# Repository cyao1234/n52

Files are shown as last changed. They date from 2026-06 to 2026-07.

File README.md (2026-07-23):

# n52 stamp

nRF52 stamp devboard with castellated holes on all 3 edges and a low profile,
allowing it to be easily soldered onto a carrier board, without having to deal with
the aQFN nRF52840 footprint. The board breaks out 36 I/O pins, and also has an
embedded 24 pin e-ink connector.

The board can operate standalone for direct wireless communication with host devices, or function as a carrier board for more complex projects. Key features include low current consumption, easy usability, and a streamlined design that prioritizes rapid prototyping and deployment.

The board's 36 broken-out I/O pins provide extensive flexibility for sensor integration, peripheral control, and data communication.

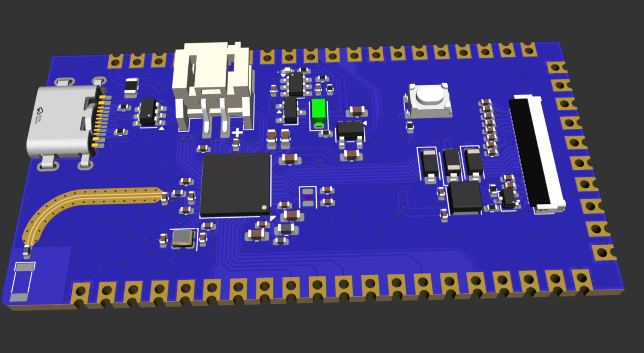
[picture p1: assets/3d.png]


Features:
- Integrated power path
- LiPo charger
- Eink driver
- Low current consumption
- Easy to use
- Castellated edges

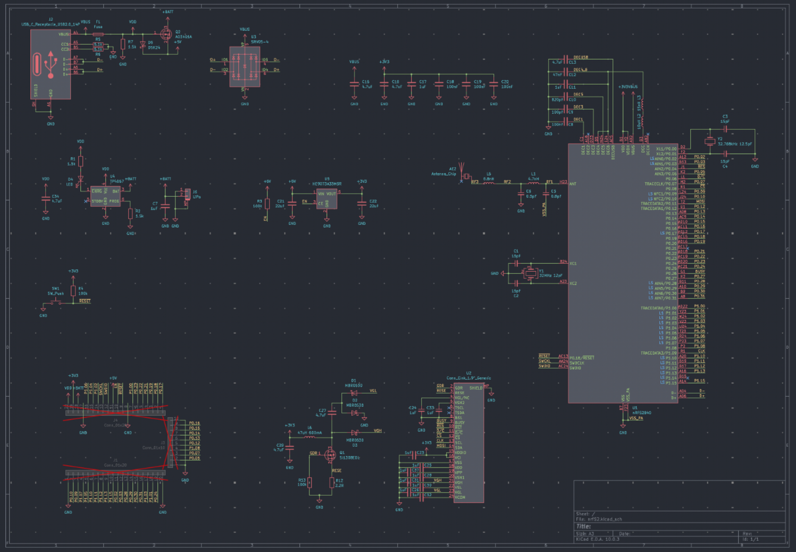
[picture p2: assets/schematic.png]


The board uses a nrf52 design to allow for bluetooth communication, and has all that is needed to directly communicate via bluetooth to a host. No external parts needed, but it can also act as an carrier board

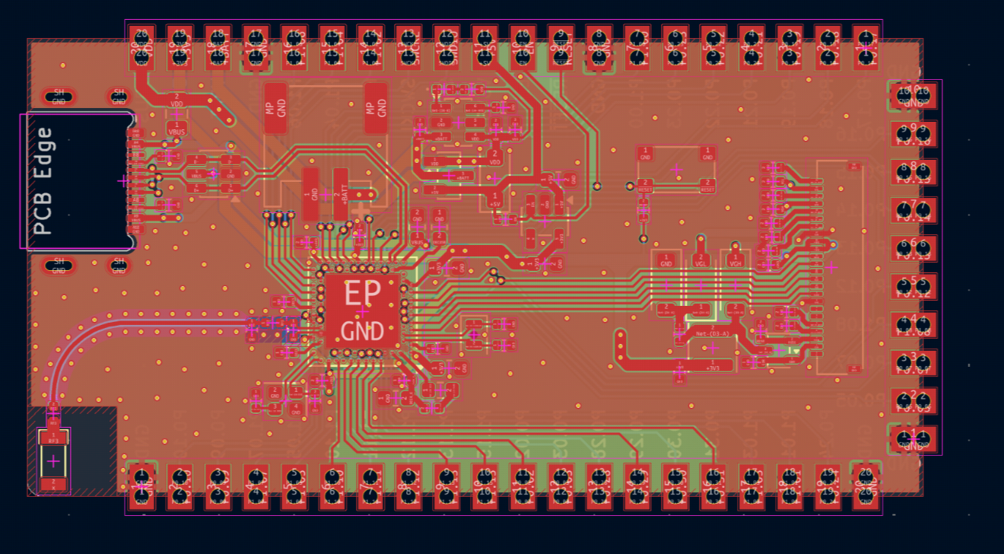
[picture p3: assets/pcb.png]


Pins:
* LED0 = P0.18
* LED1 = P0.17
* E-Ink
  * BUSY   = P0.26
  * nRESET = P0.04
  * nD/C   = P0.06
  * nCS    = P0.08
  * CLK    = P1.09
  * MOSI   = P0.11

The best way to program the board and use it is to use [Zephyr](https://docs.zephyrproject.org/)

All sources are present in the repo



| Item | Cost | Where |
| ---- | ---- | ----- |
| PCB + PCBA | $160 | JLC |

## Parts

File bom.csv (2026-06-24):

Item | Cost | Where
PCB PBCA | $160 | jlc

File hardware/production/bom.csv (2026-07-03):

Designator | Footprint | Quantity | Value | LCSC Part #
AE2 | Walsin_RFANT3216120A5T | 1 | Antenna_Chip | C127629
C1, C2, C3, C4 | 0402 | 4 | 15pF | C1548
C10 | 0402 | 1 | 820pF | C107031
C11, C17, C23, C24, C25, C26, C28, C30, C31, C32, C33, C37, C7 | 0402 | 13 | 1uF | C7472946
C12 | 0402 | 1 | 47nF | C272875
C13, C15, C16 | 0603 | 3 | 4.7uF | C380325
C18, C19, C20, C8 | 0402 | 4 | 100nF | C1525
C21, C22 | 0603 | 2 | 22uF | C380323
C27, C29, C34 | 0402 | 3 | 4.7uF | C380302
C5 | 0402 | 1 | 0.8pF | C76915
C6 | 0402 | 1 | 0.5pF | C76912
C9 | 0402 | 1 | 100pF | C1546
D1, D2, D3 | D_SOD-123 | 3 | MBR0530 | C7436545
D4, D6, D7 | 0402 | 3 | LED | C51933306
D5 | D_SOD-123F | 1 | DSK24 | C22466352
F1 | 0805 | 1 | Fuse | C46640991
J2 | USB_C_Receptacle_SHOU-HAN_TYPE-16P | 1 | USB_C_Receptacle_USB2.0_14P | C2906290
J6 | HCTL_JST_PH_HC-PH-2AWT-B_2P | 1 | LiPo | C19633668
L1 | 0402 | 1 | 4.7nH | C86065
L2 | 0603 | 1 | 10uH | C281107
L3 | 0402 | 1 | 15nH | C86059
L5 | 0402 | 1 | 6.8nH | C96056
L6 | L_APV_ANR3015 | 1 | 47uH 500mA | C7427088
Q1 | SOT-323_SC-70 | 1 | Si1308EDL | C7603347
Q2 | SOT-23 | 1 | AO3401A | C347476
R1, R11, R2, R7, R8 | 0402 | 5 | 1.5k | C114451
R12 | 0402 | 1 | 2.2R | C2906922
R13 | 0402 | 1 | 1M | C93949
R3, R4 | 0402 | 2 | 100k | C481918
R5, R6 | 0402 | 2 | 5.1k | C2906874
SW1 | SW_Push_SPST_TSA016 | 1 | SW_Push | C2888428
U1 | Nordic_AQFN-73-1EP_7x7mm_P0.5mm_Small | 1 | nRF52840 | C190794
U2 | HCTL_HC-FPC-05-09-24RLTAG-1MP_P0.5mm_Horizontal | 1 | Conn_Eink_1.9"_Generic | C5213757
U3 | SOT-23-6 | 1 | SRV05-4 | C2836319
U4 | TSOT-23-6 | 1 | TP4057 | C5380673
U5 | SOT-23-5 | 1 | HE9073A33M5R | C723789
Y1 | Crystal_SMD_2016-4Pin_2.0x1.6mm | 1 | 32MHz 12pF | C383840
Y2 | Crystal_SMD_2012-2Pin_2.0x1.2mm | 1 | 32.768kHz 12.5pF | C55208

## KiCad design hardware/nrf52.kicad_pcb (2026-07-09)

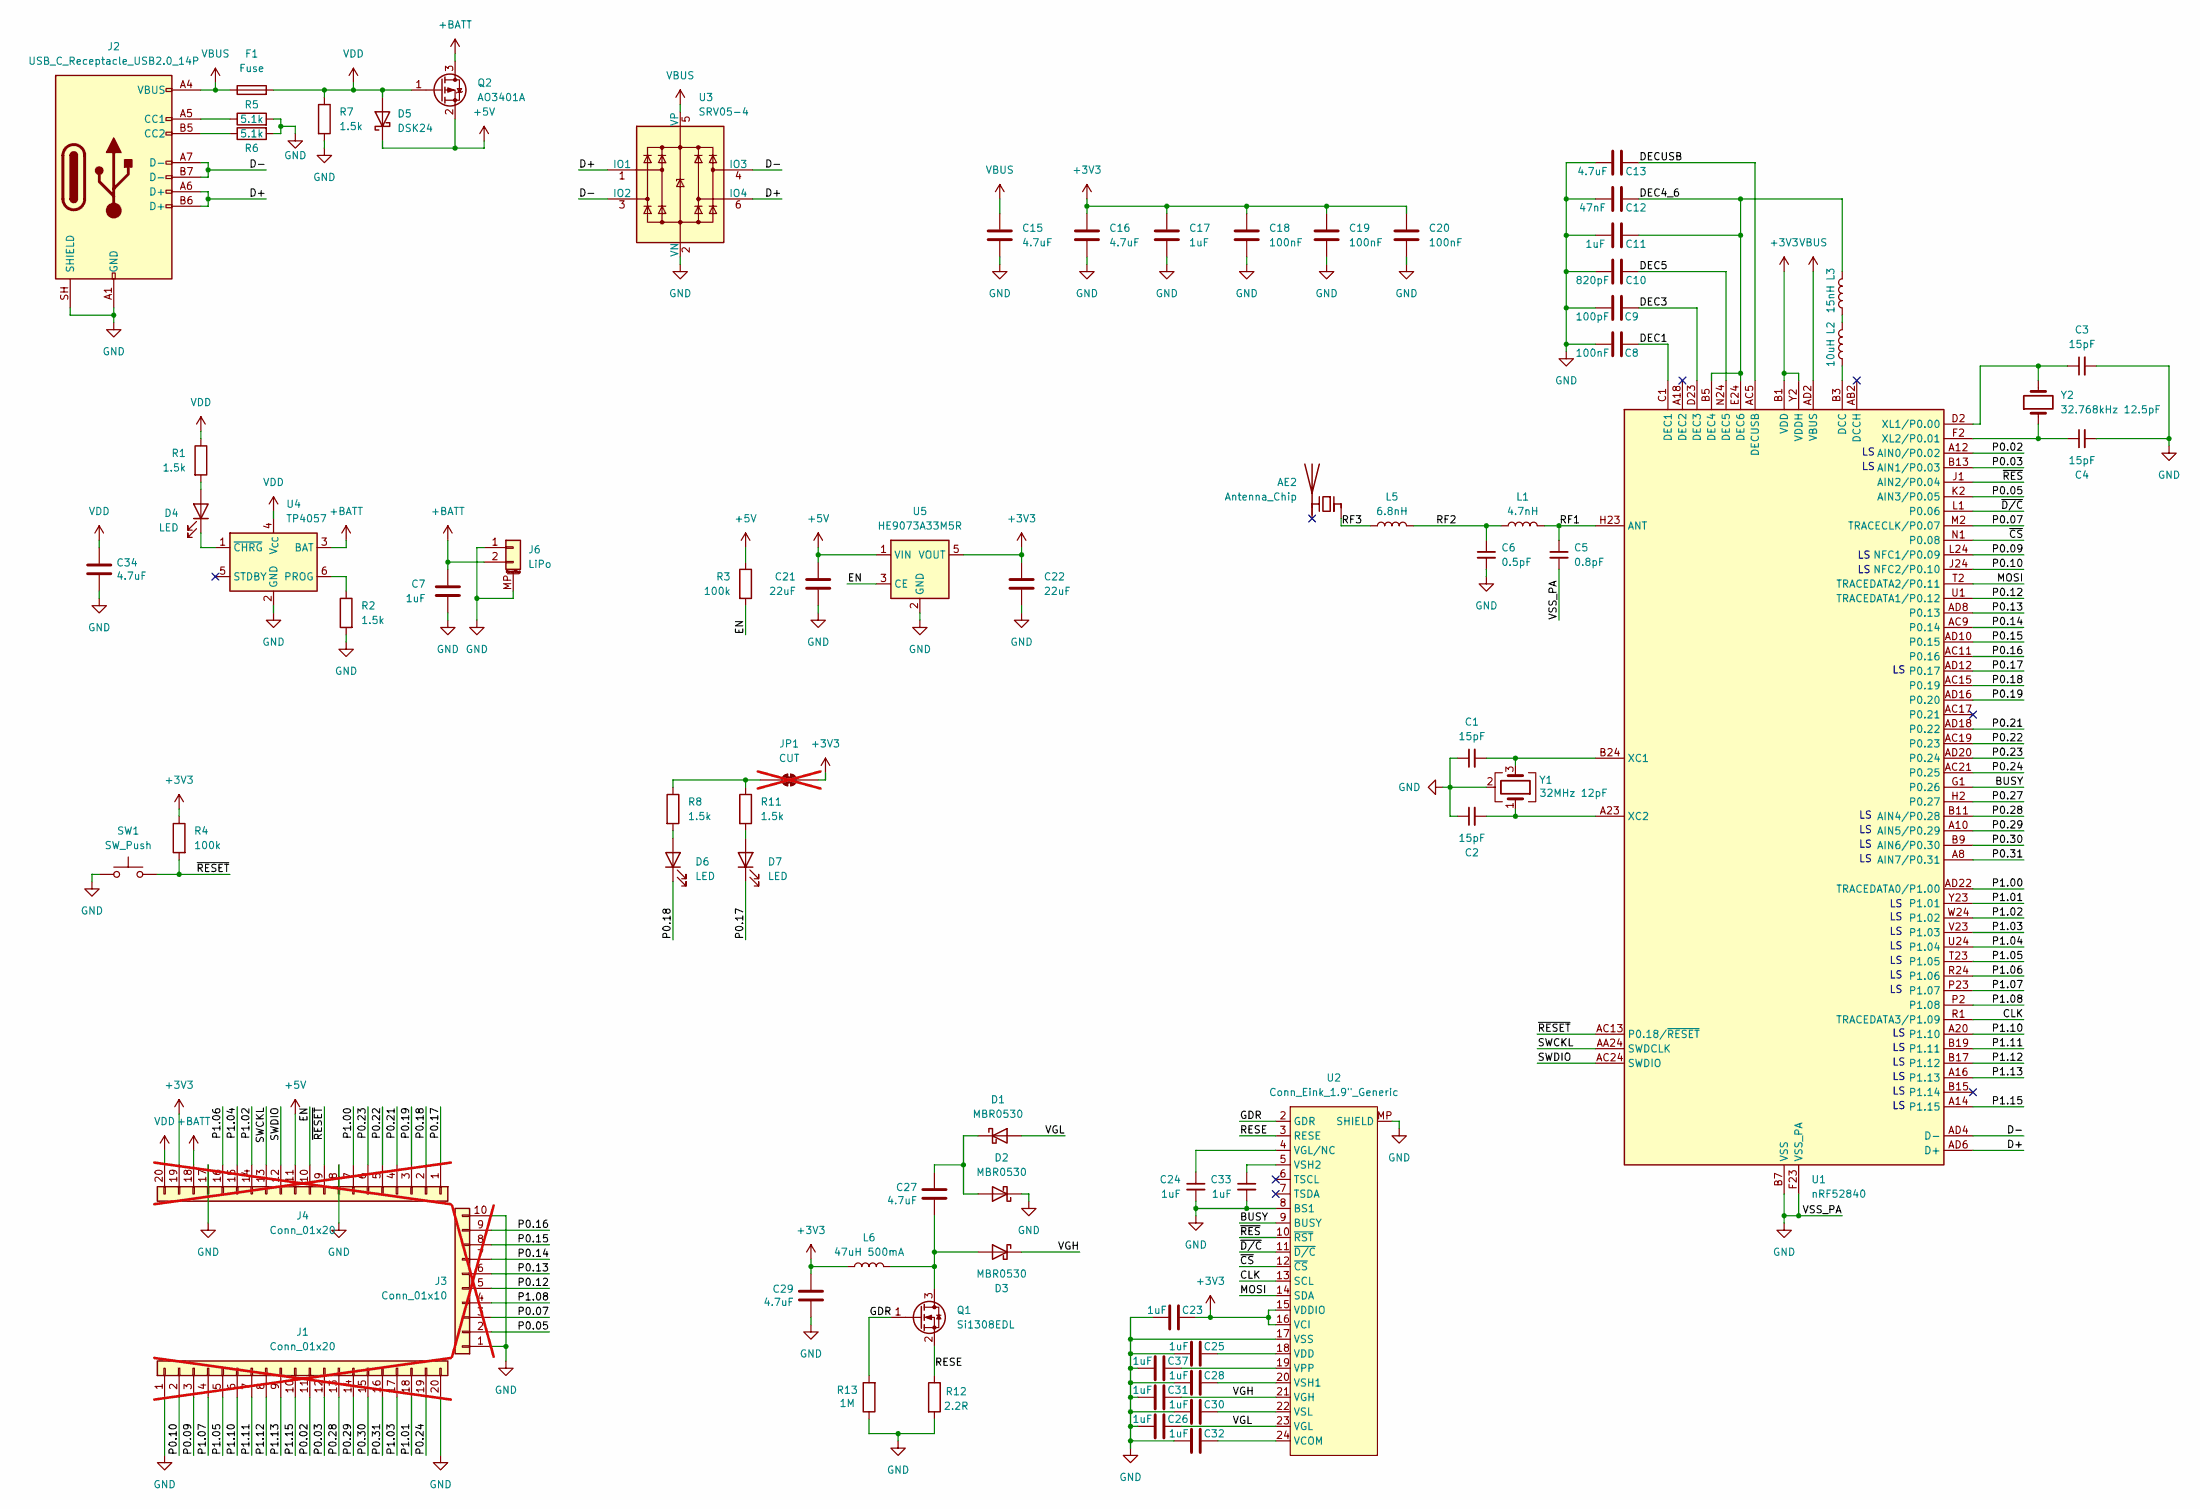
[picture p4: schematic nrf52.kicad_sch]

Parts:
AE2: Antenna_Chip; Walsin_RFANT3216120A5T; LCSC Part # C127629
C1, C2, C3, C4: 15pF; C_0402_1005Metric; LCSC Part # C1548
C5: 0.8pF; C_0402_1005Metric; LCSC Part # C76915
C6: 0.5pF; C_0402_1005Metric; LCSC Part # C76912
C7, C11, C17, C23, C24, C25, C26, C28, C30, C31, C32, C33, C37: 1uF; C_0402_1005Metric; LCSC Part # C7472946
C8, C18, C19, C20: 100nF; C_0402_1005Metric; LCSC Part # C1525
C9: 100pF; C_0402_1005Metric; LCSC Part # C1546
C10: 820pF; C_0402_1005Metric; LCSC Part # C107031
C12: 47nF; C_0402_1005Metric; LCSC Part # C272875
C13, C15, C16: 4.7uF; C_0603_1608Metric; LCSC Part # C380325
C21, C22: 22uF; C_0603_1608Metric; LCSC Part # C380323
C27, C29, C34: 4.7uF; C_0402_1005Metric; LCSC Part # C380302
D1, D2, D3: MBR0530; D_SOD-123; LCSC Part # C7436545
D4, D6, D7: LED; LED_0402_1005Metric; LCSC Part # C51933306
D5: DSK24; D_SOD-123F; LCSC Part # C22466352
F1: Fuse; Fuse_0805_2012Metric; LCSC Part # C46640991
J1, J4: Conn_01x20; Castellated_1x20_P2.54mm_Vertical; not fitted
J2: USB_C_Receptacle_USB2.0_14P; USB_C_Receptacle_SHOU-HAN_TYPE-16P; LCSC Part # C2906290
J3: Conn_01x10; Castellated_1x10_P2.54mm_Vertical; not fitted
J6: LiPo; HCTL_JST_PH_HC-PH-2AWT-B_2P; LCSC Part # C19633668
JP1: CUT; SolderJumper-2_Bridged_Pad_Small; not fitted
L1: 4.7nH; L_0402_1005Metric; LCSC Part # C86065
L2: 10uH; L_0603_1608Metric; LCSC Part # C281107
L3: 15nH; L_0402_1005Metric; LCSC Part # C86059
L5: 6.8nH; L_0402_1005Metric; LCSC Part # C96056
L6: 47uH 500mA; L_APV_ANR3015; LCSC Part # C7427088
Q1: Si1308EDL; SOT-323_SC-70; LCSC Part # C7603347
Q2: AO3401A; SOT-23; LCSC Part # C347476
R1, R2, R7, R8, R11: 1.5k; R_0402_1005Metric; LCSC Part # C114451
R3, R4: 100k; R_0402_1005Metric; LCSC Part # C481918
R5, R6: 5.1k; R_0402_1005Metric; LCSC Part # C2906874
R12: 2.2R; R_0402_1005Metric; LCSC Part # C2906922
R13: 1M; R_0402_1005Metric; LCSC Part # C93949
SW1: SW_Push; SW_Push_SPST_TSA016; LCSC Part # C2888428
U1: nRF52840; Nordic_AQFN-73-1EP_7x7mm_P0.5mm_Small; LCSC Part # C190794
U2: Conn_Eink_1.9"_Generic; HCTL_HC-FPC-05-09-24RLTAG-1MP_P0.5mm_Horizontal; LCSC Part # C5213757
U3: SRV05-4; SOT-23-6; LCSC Part # C2836319
U4: TP4057; TSOT-23-6; LCSC Part # C5380673
U5: HE9073A33M5R; SOT-23-5; LCSC Part # C723789
Y1: 32MHz 12pF; Crystal_SMD_2016-4Pin_2.0x1.6mm; LCSC Part # C383840
Y2: 32.768kHz 12.5pF; Crystal_SMD_2012-2Pin_2.0x1.2mm; LCSC Part # C55208

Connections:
+3V3: C16.1, C17.1, C18.1, C19.1, C20.1, C22.1, C23.1, C29.1, J4.19, JP1.2 (B), L6.1, R4.1, U1.A22 (VDD), U1.AD14 (VDD), U1.AD23 (VDD), U1.B1 (VDD), U1.W1 (VDD), U1.Y2 (VDDH), U2.15 (VDDIO), U2.16 (VCI), U5.5 (VOUT)
+5V: C21.1, D5.1 (K), J4.11, Q2.2 (S), R3.1, U5.1 (VIN)
+BATT: C7.1, J4.18, J6.2, Q2.3 (D), U4.3 (BAT)
/BUSY: U1.G1 (P0.26), U2.9 (BUSY)
/CLK: U1.R1 (TRACEDATA3/P1.09), U2.13 (SCL)
/D+: J2.A6 (D+), J2.B6 (D+), U1.AD6 (D+), U3.1 (IO1), U3.6 (IO4)
/D-: J2.A7 (D-), J2.B7 (D-), U1.AD4 (D-), U3.3 (IO2), U3.4 (IO3)
/DEC1: C8.2, U1.C1 (DEC1)
/DEC3: C9.2, U1.D23 (DEC3)
/DEC4_6: C11.2, C12.2, L3.2, U1.B5 (DEC4), U1.E24 (DEC6)
/DEC5: C10.2, U1.N24 (DEC5)
/DECUSB: C13.2, U1.AC5 (DECUSB)
/EN: J4.10, R3.2, U5.3 (CE)
/GDR: Q1.1 (G), R13.2, U2.2 (GDR)
/MOSI: U1.T2 (TRACEDATA2/P0.11), U2.14 (SDA)
/P0.02: J1.11, U1.A12 (AIN0/P0.02)
/P0.03: J1.12, U1.B13 (AIN1/P0.03)
/P0.05: J3.2, U1.K2 (AIN3/P0.05)
/P0.07: J3.3, U1.M2 (TRACECLK/P0.07)
/P0.09: J1.3, U1.L24 (NFC1/P0.09)
/P0.10: J1.2, U1.J24 (NFC2/P0.10)
/P0.12: J3.5, U1.U1 (TRACEDATA1/P0.12)
/P0.13: J3.6, U1.AD8 (P0.13)
/P0.14: J3.7, U1.AC9 (P0.14)
/P0.15: J3.8, U1.AD10 (P0.15)
/P0.16: J3.9, U1.AC11 (P0.16)
/P0.17: D7.1 (K), J4.1, U1.AD12 (P0.17)
/P0.18: D6.1 (K), J4.2, U1.AC15 (P0.19)
/P0.19: J4.3, U1.AD16 (P0.20)
/P0.21: J4.4, U1.AD18 (P0.22)
/P0.22: J4.5, U1.AC19 (P0.23)
/P0.23: J4.6, U1.AD20 (P0.24)
/P0.24: J1.19, U1.AC21 (P0.25)
/P0.27: U1.H2 (P0.27)
/P0.28: J1.13, U1.B11 (AIN4/P0.28)
/P0.29: J1.14, U1.A10 (AIN5/P0.29)
/P0.30: J1.15, U1.B9 (AIN6/P0.30)
/P0.31: J1.16, U1.A8 (AIN7/P0.31)
/P1.00: J4.7, U1.AD22 (TRACEDATA0/P1.00)
/P1.01: J1.18, U1.Y23 (P1.01)
/P1.02: J4.14, U1.W24 (P1.02)
/P1.03: J1.17, U1.V23 (P1.03)
/P1.04: J4.15, U1.U24 (P1.04)
/P1.05: J1.5, U1.T23 (P1.05)
/P1.06: J4.16, U1.R24 (P1.06)
/P1.07: J1.4, U1.P23 (P1.07)
/P1.08: J3.4, U1.P2 (P1.08)
/P1.10: J1.6, U1.A20 (P1.10)
/P1.11: J1.7, U1.B19 (P1.11)
/P1.12: J1.8, U1.B17 (P1.12)
/P1.13: J1.9, U1.A16 (P1.13)
/P1.15: J1.10, U1.A14 (P1.15)
/RESE: Q1.2 (S), R12.1, U2.3 (RESE)
/RF1: C5.1, L1.2, U1.H23 (ANT)
/RF2: C6.1, L1.1, L5.2
/RF3: AE2.1 (FEED_1), L5.1
/SWCKL: J4.13, U1.AA24 (SWDCLK)
/SWDIO: J4.12, U1.AC24 (SWDIO)
/VGH: C31.1, D3.1 (K), U2.21 (VGH)
/VGL: C26.1, D1.2 (A), U2.23 (VGL)
/~CS: U1.N1 (P0.08), U2.12 (~CS)
/~D/C: U1.L1 (P0.06), U2.11 (~D/C)
/~RESET: J4.9, R4.2, SW1.2, U1.AC13 (P0.18/~RESET)
/~RES: U1.J1 (AIN2/P0.04), U2.10 (~RST)
GND: C1.1, C2.1, C3.2, C4.2, C5.2, C6.2, C7.2, C8.1, C9.1, C10.1, C11.1, C12.1, C13.1, C15.2, C16.2, C17.2, C18.2, C19.2, C20.2, C21.2, C22.2, C23.2, C24.2, C25.2, C26.2, C28.2, C29.2, C30.2, C31.2, C32.2, C33.2, C34.2, C37.2, D2.1 (K), J1.1, J1.20, J2.A1 (GND), J2.A12 (GND), J2.B1 (GND), J2.B12 (GND), J2.SH (SHIELD), J3.1, J3.10, J4.8, J4.17, J6.1, J6.MP (MountPin), R2.2, R5.2, R6.2, R7.2, R12.2, R13.1, SW1.1, U1.B7 (VSS), U1.EP (VSS), U1.F23 (VSS_PA), U2.8 (BS1), U2.17 (VSS), U2.MP (SHIELD), U3.2 (VN), U4.2 (GND), U5.2 (GND), Y1.2 (G), Y1.4 (G)
unnamed: C27.1, D1.1 (K), D2.2 (A)
unnamed: C27.2, D3.2 (A), L6.2, Q1.3 (D)
unnamed: D4.2 (A), R1.2
unnamed: D4.1 (K), U4.1 (~CHRG)
unnamed: D6.2 (A), R8.2
unnamed: D7.2 (A), R11.2
unnamed: J2.A5 (CC1), R5.1
unnamed: J2.B5 (CC2), R6.1
unnamed: JP1.1 (A), R8.1, R11.1
unnamed: L2.2, L3.1
unnamed: L2.1, U1.B3 (DCC)
unnamed: C1.2, U1.B24 (XC1), Y1.3
unnamed: C2.2, U1.A23 (XC2), Y1.1
unnamed: C3.1, U1.D2 (XL1/P0.00), Y2.2
unnamed: C4.1, U1.F2 (XL2/P0.01), Y2.1
unnamed: C32.1, U2.24 (VCOM)
unnamed: C25.1, U2.18 (VDD)
unnamed: C24.1, U2.4 (VGL/NC)
unnamed: C37.1, U2.19 (VPP)
unnamed: C28.1, U2.20 (VSH1)
unnamed: C33.1, U2.5 (VSH2)
unnamed: C30.1, U2.22 (VSL)
unnamed: R2.1, U4.6 (PROG)
VBUS: C15.1, F1.1, J2.A4 (VBUS), J2.A9 (VBUS), J2.B4 (VBUS), J2.B9 (VBUS), U1.AD2 (VBUS), U3.5 (VP)
VDD: C34.1, D5.2 (A), F1.2, J4.20, Q2.1 (G), R1.1, R7.1, U4.4 (V_{CC})

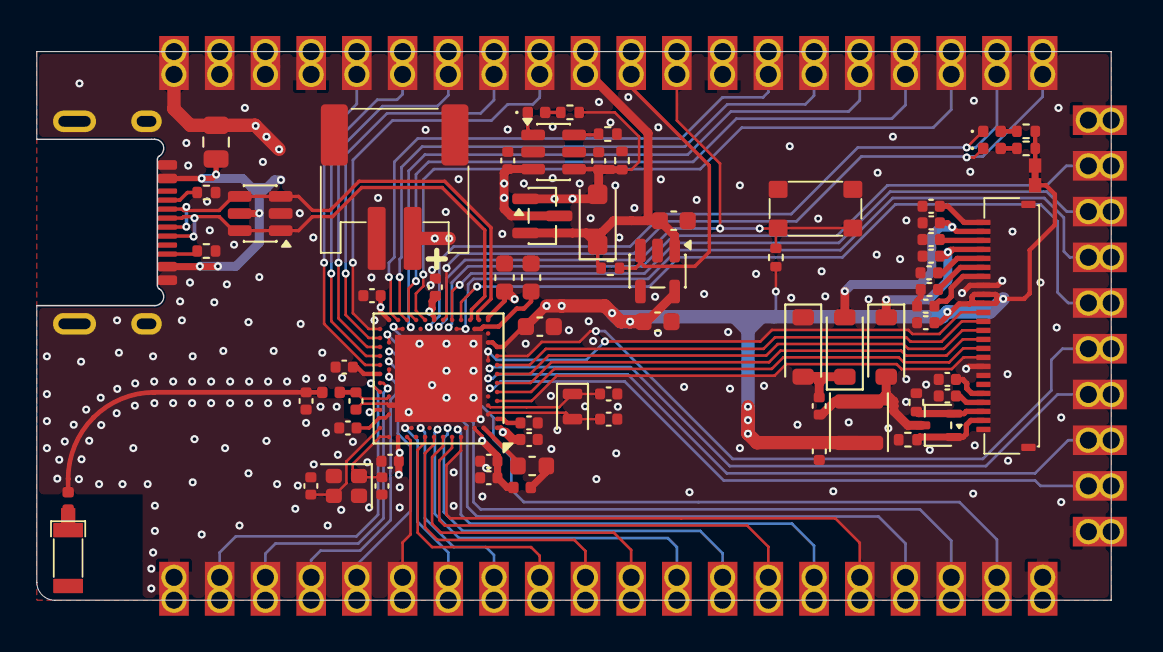
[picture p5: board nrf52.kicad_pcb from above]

Board: 4 copper layers, 59.7 x 30.5 mm, 75 parts (0 on the bottom side), 89 nets.
